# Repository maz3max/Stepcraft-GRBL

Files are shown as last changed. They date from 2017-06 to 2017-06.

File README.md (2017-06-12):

# Stepcraft-GRBL
Arduino Uno Shield for Stepcraft GRBL Controller

This is a shield to control STEPCRAFT mills via the LPT port.

(it could be easily modified to work without the LPT module directly plugged into the X1 socket)

An Arduino UNO is used with GRBL firmware and this shield.

The build option USE_SPINDLE_DIR_AS_ENABLE_PIN is needed for GRBL to work with this shield.

It works like a charm on the STEPCRAFT-2/840 with HF500 Spindle attached.

Created with KiCAD, pcb2gcodeGUI and milled on the STEPCRAFT mill itself.

The copyrights of the uploaded manuals are owned by STEPCRAFT.

http://www.netz39.de/

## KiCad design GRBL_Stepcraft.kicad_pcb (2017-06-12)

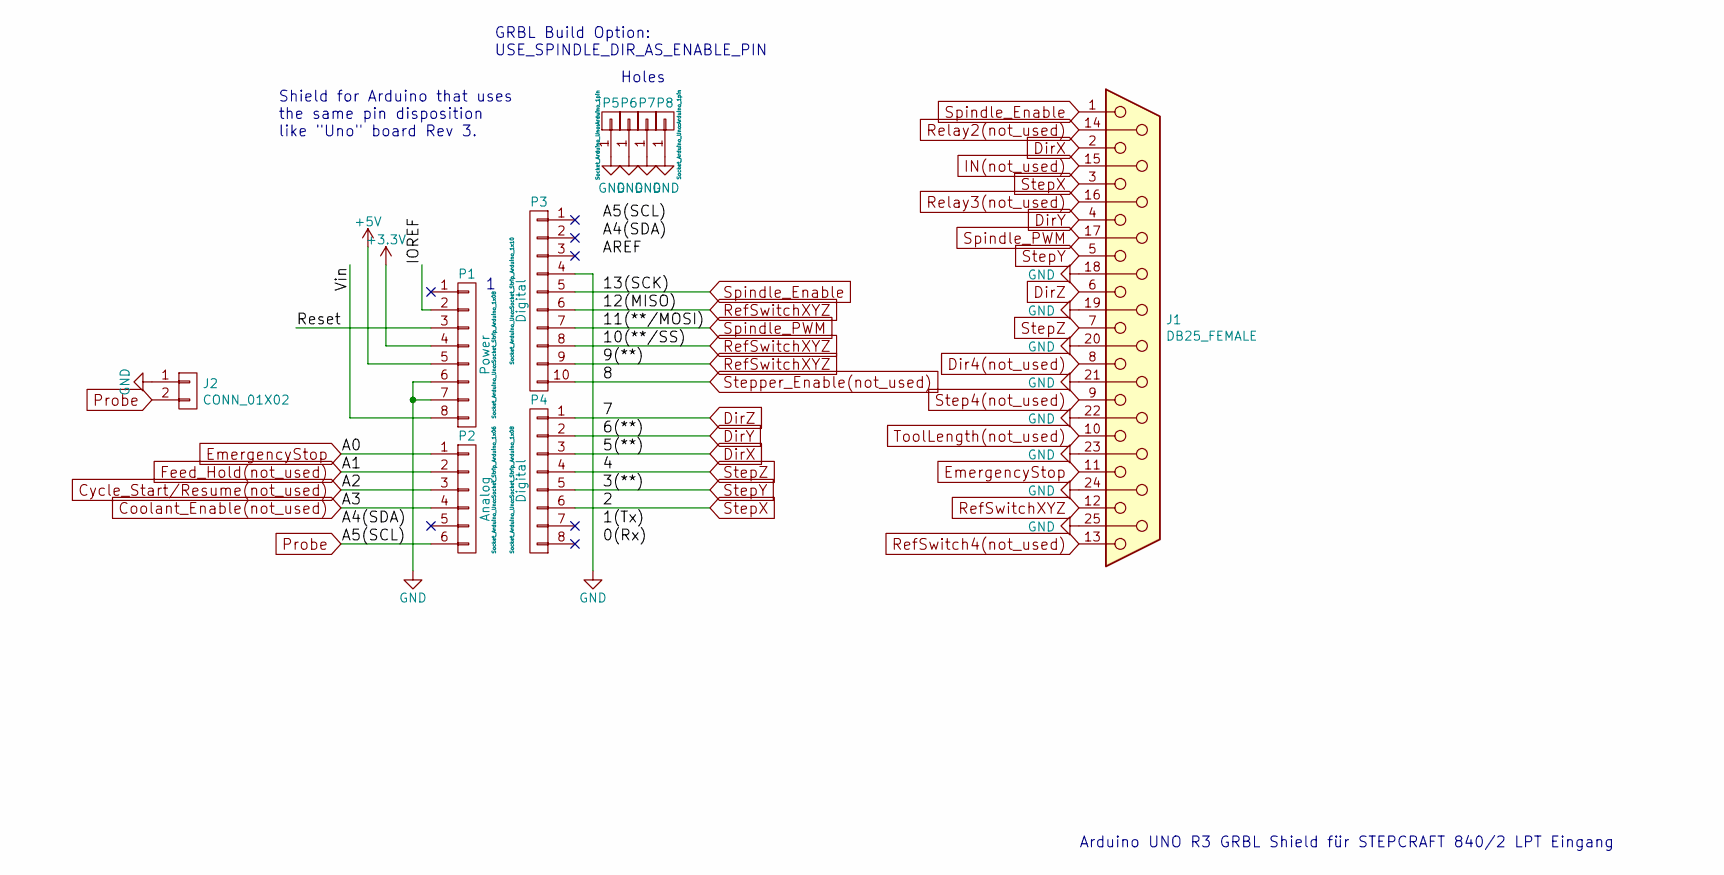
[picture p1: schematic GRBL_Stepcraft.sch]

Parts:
J1: DB25_FEMALE; DB25FC
J2: CONN_01X02; Pin_Header_Straight_1x02_Pitch2.54mm
P1: Power; Socket_Strip_Arduino_1x08
P2: Analog; Socket_Strip_Arduino_1x06
P3: Digital; Socket_Strip_Arduino_1x10
P4: Digital; Socket_Strip_Arduino_1x08
P5, P6, P7, P8: CONN_01X01; Arduino_1pin

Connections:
+3V3: P1.4
+5V: P1.5
/IOREF: P1.2
/Reset: P1.3
/Vin: P1.8
Coolant_Enable(not_used): P2.4
Cycle_Start/Resume(not_used): P2.3
Dir4(not_used): J1.8
DirX: J1.2, P4.3
DirY: J1.4, P4.2
DirZ: J1.6, P4.1
EmergencyStop: J1.11, P2.1
Feed_Hold(not_used): P2.2
GND: J1.18, J1.19, J1.20, J1.21, J1.22, J1.23, J1.24, J1.25, J2.1, P1.6, P1.7, P3.4, P5.1, P6.1, P7.1, P8.1
IN(not_used): J1.15
Probe: J2.2, P2.6
RefSwitch4(not_used): J1.13
RefSwitchXYZ: J1.12, P3.6, P3.8, P3.9
Relay2(not_used): J1.14
Relay3(not_used): J1.16
Spindle_Enable: J1.1, P3.5
Spindle_PWM: J1.17, P3.7
Step4(not_used): J1.9
StepX: J1.3, P4.6
StepY: J1.5, P4.5
StepZ: J1.7, P4.4
Stepper_Enable(not_used): P3.10
ToolLength(not_used): J1.10

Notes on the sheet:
Holes
Shield for Arduino that uses the same pin disposition like "Uno" board Rev 3.
GRBL Build Option: USE_SPINDLE_DIR_AS_ENABLE_PIN
Arduino UNO R3 GRBL Shield für STEPCRAFT 840/2 LPT Eingang

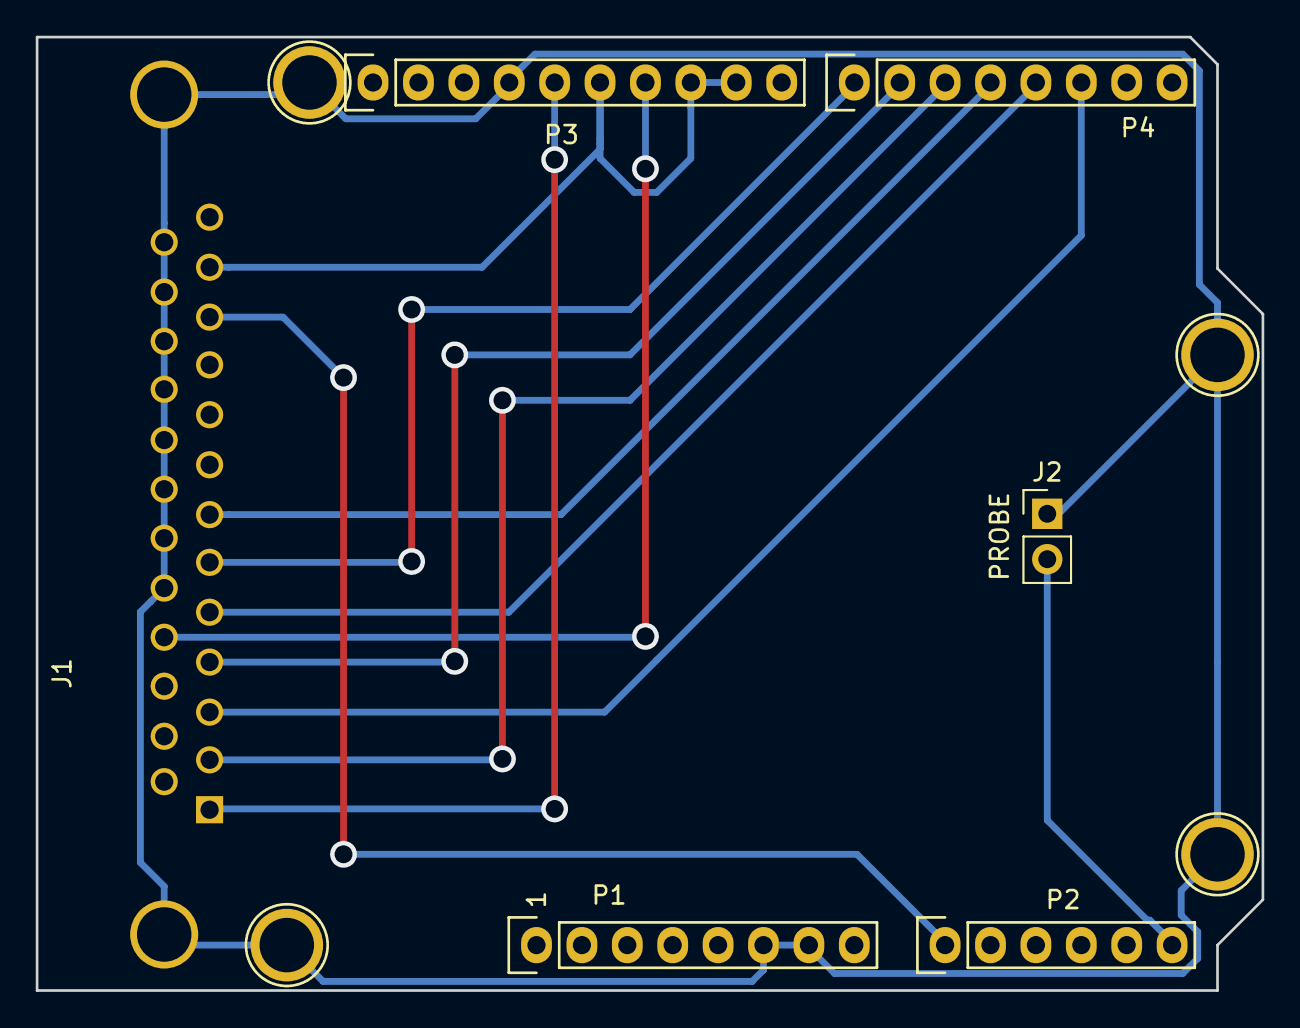
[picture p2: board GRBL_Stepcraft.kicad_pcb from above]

Board: 2 copper layers, 68.6 x 53.3 mm, 10 parts (0 on the bottom side), 12 nets.

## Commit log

2017-06-12 first working prototype
    [GRBL_Stepcraft-B.Cu.gbr, GRBL_Stepcraft-B.SilkS.gbr, GRBL_Stepcraft-Edge.Cuts.gbr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]
2017-06-12 brought probe pins to the correct side, tweaked README
    [GRBL_Stepcraft-B.Cu.gbr, GRBL_Stepcraft-B.SilkS.gbr, GRBL_Stepcraft-Edge.Cuts.gbr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]
2017-06-12 grounded holes
    [GRBL_Stepcraft-B.Cu.gbr, GRBL_Stepcraft-B.SilkS.gbr, GRBL_Stepcraft-Edge.Cuts.gbr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]
2017-06-12 repositioned components, longer wire brigdes for easier soldering
    [GRBL_Stepcraft-B.Cu.gbr, GRBL_Stepcraft-B.SilkS.gbr, GRBL_Stepcraft-Edge.Cuts.gbr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]
